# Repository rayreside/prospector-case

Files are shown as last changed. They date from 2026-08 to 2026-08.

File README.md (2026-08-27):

# Prospector Case

A compact 3D-printed case for the
[Prospector](https://github.com/carrefinho/prospector) ZMK dongle — a Seeed
XIAO and a round display, in a shell small enough to sit beside a keyboard
rather than in front of it.

42.8 × 43.0 × 35.4 mm assembled, two printed parts, 11.5 cm3 of plastic.

> ### ⚠ This is for the **beekeeb** Prospector
>
> It is cut around [beekeeb's Prospector kit](https://shop.beekeeb.com/products/zmk-wireless-dongle-prospector-diy-kit),
> and every dimension in it was measured off that build. Two things about it
> drive the whole design:
>
> - **beekeeb's adapter PCB** — the "hat" — sits on the XIAO and carries a
>   socket for the display's cable, so the link is a plugged cable at both ends
>   rather than eight wires soldered to the XIAO's pads. **That board is what
>   the case is shaped around.** It is what sets the depth, and every clearance
>   in the model is measured against it.
> - **No ambient light sensor.** There is no room for the sensor board and no
>   window for it.
>
> **On the original Prospector: this may or may not fit, and expect to modify
> it.** The upstream build solders the display straight to the XIAO's pads, so
> the stack is a different shape and sits at a different height — the hat is the
> single biggest thing this case is built around, and without it the interior is
> wrong. The numbers are all in the open and parametric, so adapting it is
> realistic work rather than a rewrite, but it is work. Start from
> [What it expects](#what-it-expects) and measure your own build first.

Every dimension is measured off carrefinho's published STLs and off the built
shell; no upstream geometry is copied. The measurements and the reasoning
behind each one are in [prospector/REFERENCE.md](prospector/REFERENCE.md), and
the design itself is documented in [prospector/README.md](prospector/README.md).

## What it expects

| | |
|---|---|
| Display | Waveshare 1.69" Touch LCD, 240 × 280, part **27057** — 41.13 × 33.13 mm, four M2 holes on a 29.93 × 22.57 pattern |
| MCU | Seeed **XIAO nRF52840**, soldered flat to the hat |
| The hat | beekeeb's adapter PCB, carrying a socket for the display's cable. The case has room for a stack **21.9 × 27.0 × 9.82 mm**, with the XIAO and its USB-C hanging *underneath* — the hat's own board sits 4.30 mm above the bottom of that stack, and its USB-C leaves along the 27 mm axis, flush with one end |
| Hat mounting | two M2 into printed pads, 17.10 mm apart, 2.65 mm in from the board's edge |
| Fasteners | **8 × M2** — four for the display into its own standoffs, two M2 × 6 for the rear cap, two for the hat |
| Cable | about 20 mm of clear run above the hat for the bundle to turn upward, which the model checks and echoes |

Those are the dimensions the case is cut to, taken off a beekeeb build.
Anything that fits inside them and puts its USB-C in the same place will go in.
**Measure yours before printing** — the three clearances that matter are echoed
on every build, so a changed number tells you at once whether it still fits.

## Printing

The STLs in [`release/`](release/) are ready to print and are what came off the
bed here — see [release/README.md](release/README.md) for figures to check them
against.

- **Shell** desk-down as modelled, with support. All of it is interior roof
  nobody sees.
- **Cap** standing on its bottom edge, with a brim.
- **0.20 mm layers**, whatever the printer: the joint steps are 0.80 and the cap
  is 1.60, and both divide exactly.
- Set the slicer's support threshold **below 44.81°**. The chamfered roof sits
  at exactly that, two tenths under the usual 45, and above the line it counts
  as an overhang when it is not one.

Assemble **hat first, display second, cap last** — the hat's screws are driven
straight down through the display opening, so the display has to go in after it.

## Building

```bash
openscad -D 'part="shell"' -D 'show_parts=false' \
         -o build/prospector_shell.stl scad/prospector.scad
openscad -D 'part="cap"' -o build/prospector_cap.stl scad/prospector.scad
```

`part` also takes `all`, which is the assembled view rather than something to
print.

`show_parts` ghosts the display and the XIAO in place. That is what you want on
screen and not what you want in an STL: left on -- and it is on by default --
the shell exports with both of them inside it, three shells and 27.20 cm3
against one and 9.62. The cap never draws them, so its line needs nothing.
Either way `tools/stlstat.py` says at once which one you have.

You do not have to build it to print it. [`release/`](release/) holds the two
STLs, checked in and refreshed with the geometry, so a `git pull` puts the
printable parts on disk -- with the figures to check them against and the
orientations to print them in.

## Checking it

`tools/` holds the verification scripts — cross-section diffs, thin-feature
detection, wall thickness, overhang and free-space analysis. They are described
in [tools/README.md](tools/README.md).

The habit they exist to support: a volume figure will tell you a part is 0.1%
off and never tell you which face moved. Measure where, not how much.

## Credits

- **[Prospector](https://github.com/carrefinho/prospector)** by **carrefinho** —
  the dongle this is a case for, and the design every dimension here was
  measured against. Licensed CERN-OHL-P-2.0.
- **[beekeeb](https://shop.beekeeb.com/products/zmk-wireless-dongle-prospector-diy-kit)**
  — the kit this case is actually cut around. Their adapter PCB is what makes
  the display a plugged cable at both ends, and it is the single component that
  determines this case's proportions. Their
  [build log](https://docs.beekeeb.com/build-guide/prospector-zmk-dongle-photo-build-log)
  is the reference for how the stack goes together.
- **[ZMK](https://zmk.dev)** — the firmware the dongle runs.
- **Waveshare** — the 1.69" Touch LCD Module (27057) the case is cut around.
- **Seeed Studio** — the XIAO nRF52840.

Named because the work stands on theirs, not because any of it is vendored:
no third-party file is checked in here, and no upstream geometry is copied.
[NOTICE.md](NOTICE.md) sets out that relationship, the licence each upstream
carries, and the reasoning about what is deliberately *not* in this repository.

## Licence

MIT — see [LICENSE](LICENSE). That covers the OpenSCAD sources, the Python
tools, the documentation and the STLs built from them.

**No warranty, and one caveat worth stating plainly:** this is a case measured
off someone else's hardware and printed on one printer. It fits a beekeeb
Prospector without the ambient light sensor. If yours differs — and an original
Prospector does differ — the numbers are all in the open. Change them and
rebuild rather than trusting these.

---

Split out of the Urchin case repository, which is where this work started; the
history came with it.

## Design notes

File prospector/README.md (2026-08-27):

# Prospector dongle case — compact

A smaller enclosure for a [Prospector](https://github.com/carrefinho/prospector)
built **without** the ambient light sensor, and with a **hat on the XIAO**
carrying a socket for the LCD cable — so the link is a plugged cable at both
ends rather than eight wires soldered to the XIAO's pads. That hat is what the
design is really shaped around.

Specifically, it is cut around
[beekeeb's Prospector kit](https://shop.beekeeb.com/products/zmk-wireless-dongle-prospector-diy-kit),
whose adapter PCB is that hat. An original Prospector solders the display
straight to the XIAO's pads and makes a differently shaped stack; this case may
or may not take one, and would need modifying to.

Model: [`scad/prospector.scad`](../scad/prospector.scad), hardware constants in
[`prospector_hw.scad`](../scad/prospector_hw.scad), measurements and their
provenance in [REFERENCE.md](REFERENCE.md). Built to `build/prospector/`.

## Where it stands

| | upstream, no sensor | this |
|---|---|---|
| Envelope | 43.2 x 51.4 x 38.0 | **42.8 x 43.0 x 35.4** |
| Enclosed | 59.86 cm3 | **42.59 cm3** |
| Plastic | 15.92 cm3 | **11.44 cm3** |
| Parts | 3 | 2 |

Same width, 16% shallower, 2.6 mm shorter, 29% less enclosed volume, 28% less
filament, and the screen keeps the upstream 55 degrees. Both parts watertight,
one shell each, zero boundary edges.

The width is the module's pocket plus a 1.7 bezel and cannot go below that.
Everything else saved is depth, and it comes from folding the boards together
instead of putting them at opposite corners of an empty box.

**The display face is flat.** `LIP_BORE` would recess the module's lip so it
finished flush, as upstream does, but that leaves a ring only 0.85 wide by
0.80 deep standing around it -- two extrusion widths and four layers, and it
does not print. Off, the face is one plane with the pocket's opening in it: the
lip lands on that face and stands 0.80 proud, and the material around the
opening is the full 1.7 bezel rather than a fragile ledge. 0.835 mm of case
shows around the lip, the same as upstream.

**And that frame is a constant width, which it was not, and getting there took
two goes.** The story is worth keeping in full, because the first attempt was
confidently wrong and every number in it was arithmetically correct.

The printed part showed a gap at each corner and nowhere else. The diagnosis
was that the section's corner radius, 7.00 and carried over as "the upstream
look", was not concentric with the pocket's 3.20: the frame narrowed toward the
diagonal, 1.70 at the sides against **0.83** at the corner, 0.829 measured off
the mesh, and the module's lip overhung the case by 0.13 mm there with nothing
under it. So the radius was made derived -- `DISP_R + DISP_CLR + BEZEL` --
which returned 4.90, and the corners filled in.

**Every one of those figures is downstream of `DISP_R`, and `DISP_R` was
wrong.** It said 3.00. Nothing had ever measured it; REFERENCE.md carries
provenance for every other number about this module and never mentioned this
one. Waveshare's panel table gives the corner as R5, and at R5 the whole
account inverts:

- **7.00 was already concentric.** It is what the identity above returns for a
  module of about R5.1, and upstream's own front face measures 0.835 of plastic
  round the lip -- uniform, corners included. Upstream had not been careless
  with a styling number; it had the radius right.
- **4.90 is now the mismatch.** Against the real module the frame runs 0.835 on
  the flats and swells to **1.705** at the corners -- the same fault mirrored,
  and visible in the model as corners that read too heavy.
- **Neither radius was ever the gap.** The pocket is cut to `DISP_R +
  DISP_CLR`, so at 3.00 it was 3.20 -- about two millimetres squarer than the
  module at every corner. The module's round corner sat in a squarer hole and
  left a crescent of open pocket. That is what the photograph shows. The
  module's own rim normally hides the pocket, and that is why it was marginal
  rather than obvious: at 3.00 the rim covers the corner by 0.865, at R5 by
  **0.037**, and a hair past that the pocket is exposed.

`DISP_R` is 5.00 now and `RIM_R` returns to 6.90 on its own. All four outlines
-- module, pocket, lip, case -- come out as the same 29 x 21 rectangle grown by
5.00, 5.20, 6.065 and 6.90, so every gap between them is constant: 0.200 of
clearance round the module, 0.865 of rim over the pocket, 0.835 of case round
the rim, corners and flats alike. The envelope does not move.

`LIP_W` and `LIP_H` were wrong too, and in a way worth naming: they were
41.33 x 33.33, read off **upstream's counterbore**, which is a hole and
therefore cut oversize. Waveshare give the module as 41.13 x 33.13. Taken as
the part it understated the frame round the lip at 0.735 against upstream's
0.835 -- which read as this case being the tighter of the two, when they are
identical. The check that settles it: with the part at 41.13 and `LIP_CLR` at
0.10, this model's own counterbore comes out at 41.33 x 33.33, reproducing
upstream's measured bore exactly.

**The lesson is not about corners.** A derived number is only ever as good as
what it derives from, and this one derived from the single figure in the file
that nothing had measured. `DISP_R = 5.00` is still the vendor's number rather
than a caliper on this part -- but it is now the *only* unmeasured input, and
three independent things agree with it where nothing agreed with 3.00.

## The clearances

The size is set by the hat and the cable, not by walls or the display. Every
gate is computed and echoed on every build, because not one of them is visible
in a render:

```
ECHO: "frame round the pocket 1.7 mm at its thinnest  (want 1.7, its width on the flats)"
ECHO: "case showing round the lip 0.835 mm at its thinnest  (want 0.835, ditto)"
ECHO: "hat clears the ceiling by 2.69987 mm  (want 2.5)"
ECHO: "plug room at the socket 7.04472 mm  (want 5.43)"
ECHO: "headroom over the hat 20.3755 mm  (want 20)"
ECHO: "tray kerbs from y 23.8195 to 41.4  (hat front 13.8)"
ECHO: "driver at the top screws 6.07027 mm across  (want 5)"
```

The first two are not clearances at all -- they are the front face, taken at
the corner rather than on the flats, because that is where the section's
rounding and the module's meet and where a mismatch between them shows first.

The 20 is measured off the real bundle, from the hat's board. The plug-room ray
carries only the plug's own reach; it used to carry the bundle's 15 mm as well,
which was double counting -- the bundle is checked by the headroom test, in the
direction it actually travels. SLACK is 2.5 because it binds at the hat's bare
front corner, where nothing but air passes.

Each of these has been wrong at least once in a way that only a number caught:

- **Hat vs ceiling** started as a test against the display's back plane treated
  as *infinite*, which silently forbade sliding the hat forward under the
  display's lower edge. The display is a bounded slab; the test is now against
  the actual pocket.
- **Plug room** was measured to the hat's front face at the module's centre
  height and read 3.58 mm. The hat is 9.8 tall and that centre is 17 up, so the
  hat is not there at all — a proper ray against its box gives 20.6.
- **Headroom** has an optimum, not a floor. The ceiling over the hat is the
  lower of the display's back plane rising toward the rear and the case's top
  face falling; the tallest point is where they cross, and the depth is chosen
  to land the hat's front edge on it.

## The screen angle is free

It is 55 degrees, the same as upstream, and it costs nothing. Every angle comes
out 43.0 deep; the shallower ones are slightly shorter:

| screen | lift | depth | height |
|---|---|---|---|
| 70 | 4 | 43.0 | 38.71 |
| 65 | 4 | 43.0 | 38.40 |
| 60 | 4 | 43.0 | 37.83 |
| **55** | **4** | **43.0** | **37.00** |

That sweep was taken at `DISP_LIFT = 4`; the case is now built at 3, one
millimetre lower and shorter throughout.

For most of this project the model insisted a shallower screen cost 5-7 mm of
depth, and it was wrong three separate ways, each found the same way -- by
being told the space was plainly visible on the assembled part:

1. **The skirt leaned forward.** Below the display the case reaches the desk by
   extending its cross-section down the *screen plane*, so at a shallow angle
   it threw material forward instead of dropping: 7.10 mm at 55 against 2.04 at
   70. Trimmed vertically at the rim, and the depth difference vanished.
2. **The ceiling test subtracted a wall that was gone.** After the seat was cut
   back to a rim the window is open above the hat, so what is overhead is the
   module itself -- not a plate 1.6 below it. And 1.6 was being taken
   vertically when it is measured along the normal. Over the hat's front corner
   that was 0.99 reported against 2.59 real.
3. **The cable's headroom was measured from the socket**, 3.92 mm above the hat
   it had been measured from.

What remains true is that a 31 mm display at 55 lies over 17.8 mm of the case's
depth against 10.6 at 70. That is real, and it is why the *interior* is
shallower behind the module at 55 -- but it does not reach the outside, because
the depth is set by the hat, not by the display.

## The form

Underneath the rounding, the upstream case is a rounded-rectangle prism whose
axis is the screen normal, trimmed by the desk plane and a vertical back wall.
This is the same prism with the back pulled forward and its top-back corner
chamfered off — which is where the volume actually was. The chamfer stops short
of a clean triangle on purpose: a single line from the apex to the bottom-back
corner has to clear a 9.8 mm brick sitting 45 mm out, and solving that puts the
case at **69 mm** deep. The hat owns the bottom-back corner.

## What holds what

| part | held by |
|---|---|
| display | drops in from the front, lip lands on the flat face, 4 x M2 from inside into its own standoffs |
| rear cap | 2 x M2 into posts at x = +/-16; carries the chamfered roof too |
| hat | two M2 into pads at its own hole positions |
| cable | two posts to zip-tie the bundle down, clear of the seat's bosses |

The display goes in from the **front** and its own lip lands on the case — not
fed in from behind and trapped under a lip on the case, which is what the model
did first. The upstream mount settles it: 39.09 x 31.09 straight through, then
out to 41.33 x 33.33 for the last **0.80 mm** before the rim. So the case never
sits over the glass, and how close the picture runs to the module's edge stops
mattering.

**The shell's own roof needed its thickness stated.** Between the display and
the cap the outer face is the chamfer, and for a long time the inner face was
just wherever the cavity prism's top face happened to fall. Those two planes
converge and cross at y = 30.2, so the roof ran out as a wedge — 0.59 mm thick
at y = 29, 0.27 at 29.9, nothing at the seam. On the printed part the feather
edge tore off and left an open slot along the top of the cap, which is what it
looked like: a gap where the cap meets the case. The cavity is now bounded by
the cap's own inner face forward of `SPLIT_Y`, so the shell's roof is the same
1.6 plate the cap is and the two butt flush. Behind the split that bound does
nothing, which leaves the deliberate overrun as the only thing describing that
surface — the arrangement that got the self-intersections down from 219.

The seat is a 1.6 rim with an 8 mm pad at each screw, and nothing in between.
It was a 7.25 ledge until it became clear it was holding nothing: the module
front-loads and its lip lands on the face, so nothing can fall inward. All the
ring ever carried was the four screws. Before that it was 2.50, and all four
holes fell inside the connector window with no material under them — a case the
display could not be screwed to, invisible in every render.

The cap is a **bent panel**: the vertical back and the chamfered roof in one
piece. It has to be. The display's upper screws run along the screen normal,
and with the roof fixed to the shell the driver's line is blocked by the roof's
rear edge; taking the roof off with the cap clears it, and the fattest shaft
that then reaches them is **5.61 mm**, echoed on every build. The alternative
was access holes through a visible face. It is also much the larger surface, if
it is going to carry anything printed on it.

> The cap was split into a roof tile and a back plate for three commits, so
> each half could print the way it wants — the tile flat with its show face up,
> the back plate on its bottom edge — held by a ledge at the front and a groove
> at the rear, with no third screw. The mechanism was sound and it is in the
> history at `bee6b9a`. What sank it is that a 1.6 mm plate has to be split
> three ways to make that joint: lip 0.80, groove 0.80, tongue 0.65, with a rib
> hanging below. No margin anywhere, and the rib was rooted in **0.15 mm** of
> neck until a side elevation caught it — every mesh check passed, because
> 0.15 mm of neck is still one shell.
>
> The bent panel's only cost is that the roof's outer face prints against the
> build plate. The split's cost was every feature in it having none to give.

### The seam

The cap does not merely meet the shell at y = 30, it laps under it. The shell
keeps the outer 0.80 of the chamfer for 2 mm past `SPLIT_Y`; the cap's roof tip
is the inner 0.80 and stops 0.30 short. Sectioned at y = 31 the shell holds
24.713..25.840 and the cap 23.585..24.713 — meeting on a plane, so the shell
also holds the roof down rather than only abutting it.

It is a lap because the butt did not work, for a reason that showed up only on
the part. Two faces in different planes — the back at y = 41.4 and the roof tip
at y = 30 — were both required to close in the same instant, on two separately
printed parts. Whichever lands first wins, and it was the tip: the back plate
could not close, the screws kept pulling, and the roof bent backwards. The
clearance now goes in y, where the lap hides all but a 0.3 line.

**The lesson, which cost a print.** A zero-volume intersection between two parts
says they do not overlap. It does not say they can be assembled. A face square
to the direction of travel must not touch before the seating face does, and no
static check in this repo can see the difference.

**And a second lesson, from the same seam: that section above was computed, not
measured, and for a long time it was not true.** The lap is described here as
the outer 0.80 of the chamfer, and `seam_lip()` draws exactly that -- but it was
never unioned into the shell. Leaving it out of `cap_void()` only stops the
cap's region taking it away; it does not put it there. What was actually left
behind the split was whatever `outer()` minus `hollow()` happened to leave, and
behind `SPLIT_Y` the cavity is deliberately unbounded above, so the roof there
was governed by the cavity prism's own top face -- which crosses the chamfer.

The lap came out as a WEDGE, and every millimetre of it was under one extrusion
width:

    y = 30.0   0.44 mm       y = 31.2   0.08 mm
    y = 30.5   0.30          y = 31.4   0.02
    y = 31.0   0.14          y = 31.5   nothing

So from y = 31.5 to where the cap's own skin starts at 32.3, **no part owned the
roof at all** -- an open slot about 1.5 mm wide, plus whatever of the feather
edge tore off in the printing. It is the same failure as the roof forward of the
split, which was fixed by bounding the cavity with the cap's inner face; this
side kept the fault, because the fix was never applied to the material the lap
is made of.

`seam_lip()` is unioned on now. The lap is 0.80 thick over its whole 2 mm, the
figures above are measured off the mesh rather than derived, and the 30.7 x 0.40
sliver that `thin.py` had been reporting at z = 26 -- and that had been written
off as inherent to the joint -- is gone with it.

**The line that is left is meant to be there, and it is now two numbers rather
than one.** `SEAM_CLR` was doing both ends of the lap at 0.30, and they are not
the same problem:

- The **tongue's tip**, against the shell's roof end at `SPLIT_Y`. It sits under
  the lap where nothing can see it, and it is the clearance that bent the roof
  backwards when it was zero. `SEAM_CLR`, still 0.30.
- The **cap's shoulder**, where its skin steps back up to full thickness against
  the trailing end of the lap. Neither part owns the roof across it, so this is
  the visible line -- and on a 45 degree roof it opens up by 1/cos, showing 1.41
  times its own width. At 0.30 that was 0.42 mm of open groove 0.80 deep, which
  is a mark, not a hairline. `SEAM_SHOW`, now **0.15**, showing 0.21 and echoed
  on every build.

Tightening only that end is safe in a way tightening both would not be. If the
shoulder binds, the cap stops 0.15 short of a seat two screws are pulling it
onto, over a step 0.80 deep, and it shows as a gap at the back plate. If the
**tip** binds it levers the whole roof, which is the failure this joint exists
to avoid. What the shoulder has to absorb is the difference between two
nominally 9.4 mm runs from each part's seating face -- and both are plain y
positions, vertical walls placed by XY motion on both parts rather than
layer-quantised, so it is XY accuracy twice over and nothing worse.

### The rear screws

The pilot has been wrong in both directions, which is worth recording because
neither number was arbitrary and both were still wrong:

| | | |
|---|---|---|
| 2.10 | screws spun straight through | sized for the M2.5 in upstream's BOM, above an M2's own major diameter |
| 1.60 | driver cammed out; head crushed into the plate | 0.8 x major, the textbook thread-forming pilot |
| **1.70** | | the pilot the **hat** screws use — same screw, same plastic, and the only one here that has been driven without complaint |

Both now come off `M2_PILOT`, so they cannot drift apart again.

The "head sinks in" half of that was the same fault seen from the other end,
not a second one: 4.4 mm of thread to form at once takes more torque than an
M2 head will take, and once the driver slips the head crushes 1.6 mm of plate.
Peak torque is the pilot times how much thread is being formed at once, and the
second term was free — `CAP_FREE` bores the post's mouth to clearance for
1 mm first, so an M2 x 6 forms **3.4 mm** of thread rather than 4.4, and finds
the hole square before it starts biting. The bore's lip is broken by 0.30 so
the head beds on flat material.

`CAP_HEAD` is `"pan"`. If the screws turn out to be **countersunk**, set it to
`"flat"` and the chamfer becomes a real 90-degree seat to `CAP_HEAD_D` instead
of an edge break — with a conical head in a straight 2.2 hole the head wedges
and buries itself no matter what the pilot does.

The hat drops onto pads at its own hole positions and takes two M2. With the
seat cut back to a rim a driver comes straight down through the display
opening, so the order is hat first, display second.

`MCU_HOOKS` adds rails along the top of both side kerbs, which capture the hat
without screws -- the kerbs already stand 0.9 mm proud of the board, so it
costs 1.2 mm of height and 99 mm3. Off, because the screws already do the job
and the rails' undersides are 107 mm2 of horizontal ledge to support. Worth
remembering that rails work where hooks did not: an earlier version reached
back over the hat's front corners, so the board had to slide *into* them, and
everything ahead of it blocked that in turn.

**The kerbs themselves stop at y = 25.2, not at the hat's front edge.** The
display's two lower access bores come down through exactly that space -- they
leave the bosses at 55 degrees and reach the desk around y = 22 -- and the
tray's outer corners sit on their line. Run the full length, the bores notch
each kerb over 8 mm of a 1.5 mm wall, which is what it looks like on the part.
`KERB_Y` is derived from the bore rather than typed in, and it is deliberately
about 2 mm conservative: it asks the whole 5 mm bore to be clear, not just the
0.29 mm sliver that actually overlaps, so it does not quietly go wrong if the
kerb moves. 16.2 mm of kerb is left, against the two screws at the front and
the cap behind. What the bores still graze is the 0.6 mm standoff pad, out
where it overhangs the board -- and they pass through the floor there anyway.

**The XIAO and its USB-C hang underneath**, propping the board 4.30 mm above the
bottom of the stack. Missed on the first test print, where the pads had been
drawn up to the stack's underside with no board there to meet them.

The alternative, if a bolted hat is ever wanted, is to move the pads onto a
tongue on the rear cap: the hat then bolts to the cap on the bench and the pair
slide in together. One more feature, no more parts.

> A feature that adds no material can still break the mesh. With `BOSS_H = 0`
> the seat's boss cylinders sat entirely inside the plate that already existed
> — zero volume — but their front faces landed exactly on the seat's front
> plane, and that coplanar contact was the shell's one non-manifold edge. The
> fix was not to draw them. Found by elimination: `outer()` and
> `outer() - hollow()` were both clean, so it had to be something unioned on
> afterwards, and the edge sat exactly on `w = 0`.
>
> Anything added inside the shell has to be unioned **after** `hollow()` is
> subtracted, or the cavity swallows it — built the wrong way round, the seat
> bosses, the tray and the cap posts all vanished and the shell came back at
> exactly the volume it had without them. Then they have to touch something: a
> post floating at screw height and a tray sitting flush on the floor both came
> out as separate shells until given a foot and a 0.2 mm overlap.

## Printing

**Shell desk-down as modelled; cap standing on its bottom edge, with a brim.**
Measured with `tools/overhang.py`, and it contradicts the obvious guess — that
the sloping interior roof made desk-down the bad orientation:

| | support | bed contact | height |
|---|---|---|---|
| **shell, desk-down** | 555 mm2 | **1446 mm2** | 35.4 |
| shell, front face down | 538 mm2 | 240 mm2 | 36.7 |
| shell, back face down | 504 mm2 | 117 mm2 | 41.4 |
| **cap, as modelled** | 638 mm2 | 69 mm2 | 26.8 |
| cap, laid flat | 0 mm2 | 378 mm2 | 13.0 |

**Read that table with the threshold in mind.** At `DISP_LIFT = 3` the chamfer
sits at **44.81 degrees** from horizontal, two tenths of a degree under the
45 the tool defaults to, and the whole 638 mm2 on the cap is that one surface
crossing the line. At `--thresh 44` the same orientation scores 20 mm2. Nothing
about the part got harder to print between 46.5 degrees and 44.8; set the
slicer's threshold to 40 and the cap still prints standing, as it did before.

All the shell's support is interior roof that nobody sees. The cap needs almost
none standing up, but 69 mm2 of contact under a 27.6 mm part wants a brim.

The tool ignores shallow faces within 1 mm of the bed, which matters: without
that the 0.80 mm counterbore ledge scored 153 mm2 against an orientation where
it was really just the second layer. **It also hides things.** On the split
roof tile it reported a clean 0 mm2 while a 2.9 mm ledge floated 0.80 above the
bed -- inside the exemption, and a mating face. Pass `--above 0` before trusting
a zero, and read the heights rather than the total.

Settings the geometry dictates, whatever the printer: **0.20 layer height**,
because the joint steps are 0.80 and the cap is 1.60 and both divide exactly;
thin-wall detection on; and support for the shell only. The cap standing up
needs almost none, and support anywhere near the display seat has to come back
out through the pocket.

## Still to do

- ~~Shell and cap meet at exactly 0.00~~ — **this was the wrong conclusion, and
  the printed part proved it.** Intersecting the two solids gives zero volume,
  and I read that as a butt joint located by two screws, which is what it should
  be. Right about the y = 41.4 plane, blind to the other one: the cap's roof tip
  met the shell's roof edge at y = 30, also at exactly 0.00, and that face is
  square to the direction the cap travels to seat. On the part the tip landed
  first, the screws kept pulling, and the roof bent backwards — opening the very
  gap the joint was meant to close. The seam is a lap now; see below.
- **The cap's bottom-back fillet reaches 0.12 mm from the hat.** The `BACK_R`
  rounding where the cap meets the desk curves forward of y = 41.4 by 0.18, and
  the hat's rear edge is at 41.1. Positive, but it is the tightest unintended
  clearance in the case and nothing checks it.
- **Three self-intersecting triangle pairs and twelve degenerate faces** remain
  in the shell, out of 3394. Down from 219, which is what the slicer was
  visibly choking on. Slicers deal with what is left routinely.
- **`PLUG_H` is the one estimated number** — 4 mm, inferred from the hat's 9.82
  stack rather than measured. The plug-room check has 8.79 against a need of
  5.43, so it does not fail until `PLUG_H` exceeds 7.36.
- **The socket's position across the module is still unknown**, only that it is
  on the left. `CONN_SLOT_*` is a generous relief rather than a fitted pocket.
- **No full assembly has been printed.** The shell has been through several
  test prints; the cap has not. The rear screws have, and drove badly enough to
  change the pilot twice — see above.

## Layouts that were considered and dropped

| | screen | depth | height | why not |
|---|---|---|---|---|
| slab, boards back to back | 55 | 41.6+ | 36.5+ | `GAP` must be 15 for the bundle, which puts it past 45 deep; stands on 13.7 mm of base |
| tail out the back | ~90 | 42 | 34 | needs a near-vertical screen |
| hat under the display | 75 | 30.0 | 52.8 | 52.71 cm3 — same volume, trades 19 mm of depth for 16 of height |
| hat turned, USB out the side | 70 | ~42 | 38.7 | 5 mm shallower, but the USB-C leaves sideways |

`scad/prospector_slab.scad` still builds the slab if it is ever wanted.
`DISP_LIFT = 18, DEPTH = 30, TILT = 75` builds the hat-under variant;
`-D MCU_DY=MCU_D -D MCU_DX=MCU_W` turns the hat.

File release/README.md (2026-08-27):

# Printable exports

The two STLs beside this file are what comes off `scad/prospector.scad`. They
are checked in so that a `git pull` puts the printable parts on disk -- the
repository is the sync channel, and not everyone who wants to print this has
OpenSCAD installed.

Built with OpenSCAD 2021.01, from the commits that unioned the seam lip into
the shell and tightened the shoulder behind it. Before them the lap over the
rear cap was a feather edge, with an open slot about 1.5 mm wide behind it and
a 0.42 mm groove behind that; what is left is a 0.21 mm line.

| | shell | cap |
|---|---|---|
| triangles | 3550 | 864 |
| bounding box | 42.800 x 41.400 x 35.368 | 42.800 x 12.700 x 25.408 |
| volume | 9.6219 cm3 | 1.8788 cm3 |
| shells | 1 | 1 |
| non-2-manifold edges | 0 | 0 |
| boundary edges | 0 | 0 |

`python tools/stlstat.py release/prospector_shell.stl` reproduces that column,
which is the check that you have the file you think you have. The shell at
27.1 cm3 and three shells is the one with the ghosted display and XIAO
exported inside it -- see below.

## Printing

**Shell desk-down as modelled.** 678 mm2 of support and **1414 mm2** of bed
contact, against 117 mm2 back-down -- and all of that support is interior roof
nobody sees. Measured with `tools/overhang.py`, not reasoned about; it
contradicts the obvious guess about the sloping roof.

**Cap standing on its bottom edge, with a brim.** Its 622 mm2 is very nearly one
surface, the chamfer, sitting at 44.81 degrees -- two tenths under the 45 the
tool defaults to. At `--thresh 44` the same orientation scores **20 mm2**, so it
needs almost no support standing up; what it does need is the brim, because
69 mm2 of bed contact under a part 25.4 mm tall is not enough on its own.

The shell reads the same way: 678 mm2 at 45 degrees, **435** at 44. Set the
slicer's threshold below the chamfer's own angle and most of both figures goes
away, because most of what they count is that one surface.

**0.20 layer height**, whatever the printer: the joint steps are 0.80 and the
cap is 1.60, and both divide exactly. Support for the shell only -- anything
near the display seat has to come back out through the pocket.

The full orientation table and what the overhang tool hides are in
[../prospector/README.md](../prospector/README.md).

## Rebuilding

```bash
openscad -D 'part="shell"' -D 'show_parts=false' \
         -o release/prospector_shell.stl scad/prospector.scad
openscad -D 'part="cap"' -o release/prospector_cap.stl scad/prospector.scad
```

`show_parts` is on by default and ghosts the display and the XIAO in place. On
screen that is the point; in an STL it is the display and the XIAO exported
inside the shell -- three shells and 27.20 cm3. The cap never draws them, so
its line needs nothing.

Two things follow from checking these in:

**They go stale silently.** Nothing rebuilds them. Anything that changes the
geometry has to rebuild both and commit them in the same commit, or the files
here describe a case that no longer exists.

**Do not diff them by hash.** OpenSCAD does not emit facets in a stable order,
so two builds of the same tree give two different files with the same triangle
count and the same vertex set. `stlstat.py` is the comparison that means
anything; `md5sum` is not.

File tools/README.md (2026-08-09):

# Verification tools

Used to check `scad/prospector.scad` against measurements taken off the
upstream STLs. The measurements are the ground truth; the model is checked
against them, never the other way round.

Requires Python 3 and numpy. Both scripts read ASCII and binary STL.

## `stlstat.py` — bulk properties

```bash
python tools/stlstat.py build/prospector_shell.stl
```

Reports triangle count, bounding box, volume, shell count, and edge
manifoldness. It reproduces the figures published in the root README exactly,
which is the check that it is measuring correctly.

Note: the non-2-manifold edge count here (25 on the top) is higher than the 17
the README cites from Blender — a different counting convention. Both agree on
zero boundary edges, which is what actually determines watertightness.

## `slice.py` — cross-section areas

```bash
python tools/slice.py <reference.stl> <candidate.stl> 2.0 3.0 4.5 8.5
```

Prints the cross-sectional area of both meshes at each z, with the delta.
Volume alone says *how much* two parts differ; this says *where*. A constant
delta across a z band means both parts are prismatic there and the section
itself is wrong. A delta that varies with z means the reference has features
the candidate lacks.

## `clusters.py` — where two sections disagree

```bash
python tools/clusters.py <reference.stl> <candidate.stl> 6.0
python tools/clusters.py ref.stl cand.stl 6.0 0.025 0.02   # step, min area
```

Labels the disagreement into connected clusters and gives each one's extent, in
both directions separately. `slice.py` says how much and at what height; this
says whereabouts, which is the part that leads to a cause.

Splitting the two directions matters. The mountains once read −0.14% on volume
because a 12 mm² deficit on one wall was cancelling a 12 mm² surplus elsewhere;
fixing the deficit made the total look worse and the part better.

## `thin.py` — features too thin to print

```bash
python tools/thin.py build/prospector_shell.stl 6.0 0.20
```

Opens the section with a disc and reports what the opening removed — anything
narrower than twice the radius cannot hold the disc. Pass about half a nozzle
width. Convex corners lose only r²(1−π/4), so a hit near that size is noise.

This found what diffing could not. The printed mountains carry no feature under
0.4 mm anywhere; the port had eighteen, one of them a 5.70 mm tongue just
0.047 mm wide, which a 0.10 mm section grid had stepped straight over.

It also brackets a threshold from both sides: if the printed part drops a 0.437
sliver but keeps a 0.485 strip, the radius that reproduces it is pinned to a
window rather than fitted to a curve.

## `fitedge.py` — is this edge straight, and at what angle

```bash
python tools/fitedge.py <part.stl> 6.0 128.4 135.0 44.0 86.0 max
```

Traces one boundary of the window row by row and fits a line. The residual is
the useful part: at the raster floor (`step/√12`) the edge is exactly straight
and the angle can be trusted; well above it, the window spans more than one
edge and the fit means nothing.

Check an angle at two heights before believing it. If they differ the part
isn't prismatic and one section was never going to describe it.

## `raster.py` — shared section fill

Not run directly. `clusters.py`, `thin.py` and `fitedge.py` all fill a section
onto a grid through it.

Both crossing tests are half-open rather than strict, which is not fussiness:
the strict form drops any segment with an endpoint exactly on the scan line,
and on a tessellated mesh vertices land on round coordinates constantly.
`probe.py` had that bug and it dropped two of four crossings at y=20 on the
printed mountains — and because the survivors are paired off in order, the
spans it printed were plausible and wrong.

**Resolution is the recurring trap in all of these.** A feature thinner than
one cell can vanish entirely. An edge that merely crosses a cell boundary
during a parameter sweep reads as a whole cluster appearing, which looks like a
cliff in the numbers and is not one. Keep the step well under the smallest
thing being judged.

## Seeing anything in the OpenSCAD GUI

Two settings do almost all the work, and both are off by default:

- **View -> Show Edges.** Without it a plate is a flat slab and features
  disappear into it.
- **F6 (Render) rather than F5 (Preview).** Preview draws subtracted volumes
  as green ghosting; F6 shows the actual solid.

Perspective rather than orthographic also helps read depth. Even so the
viewport has no shading worth the name -- for judging outside shape, export
with `build.py` and open the STL in a real viewer.

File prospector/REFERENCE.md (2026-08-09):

# Prospector dongle — measured reference

Everything here was measured off the upstream case
([carrefinho/prospector](https://github.com/carrefinho/prospector), `case/`),
not read off a datasheet. Waveshare publishes no usable drawing for the module
and the vendor pages return 403 to anything but a browser, so the display
outline below is derived from the pocket that holds it.

Tools used: `tools/loops.py` (tilted sections, loop by loop),
`tools/stlstat.py` (bulk properties), `tools/void.py` (where the air is).

## What the stock case costs

| | |
|---|---|
| Envelope | 43.2 x 51.4 x 38.0 mm |
| Convex-hull volume | 59.86 cm3 |
| Plastic | 15.92 cm3 |
| Free interior | 43.94 cm3 — **73% air** |

Parts: `main_body_no_sensor` 7.137 cm3, `rear_cap` 5.785 cm3,
`disp_mount` 3.002 cm3. All three are watertight, 0 boundary edges.

The three STLs share one origin, so they can be imported together and measured
as an assembly without any transform.

## Why it is that size

Not the width. The front face is 43.0 x 35.0 mm around a 39.09 x 31.09 pocket:
a **1.95 mm bezel**, already near the floor. About 0.5 mm is recoverable there
and no more.

The depth and the height. The two boards sit at opposite corners of an empty
shell — display at the front top, XIAO flat on the floor at the back — so the
wire run is a ~45 mm diagonal across a box that is otherwise air. The bezel
frame alone is 10.6 mm deep from the body face to the front rim, most of that
a styling recess around the glass.

## Screen plane

**55.000 degrees from horizontal.** Recovered from the area-weighted face
normal (0, -0.819, 0.574) = (0, -sin 55, cos 55), which is exact to the 0.01
rounding of the normal cluster.

Nothing about the display is measurable in the export frame. `tools/loops.py
--tilt 55` sections in the screen's own frame; `u` is across the screen, `v` up
it, `w` out of it, with `w = 0` at the export origin and `w` increasing
forward.

| Feature | w (mm) |
|---|---|
| Body screw tabs | 4.40 -> 6.40 |
| Body front face (pocket floor) | 6.40 |
| Mount screw tabs | 6.50 -> 8.50 |
| Mount front rim | 17.00 |

## Waveshare 1.69" Touch LCD Module (27057)

| | |
|---|---|
| Outline | **39.09 x 31.09** mm pocket -> module ~39.0 x 31.0 |
| Mounting holes | 4 x M2, **29.93 x 22.57** mm pattern, 2.40 mm clearance |
| Orientation | landscape — 280 px across, 240 px up |
| Active area | 32.58 x 27.93 mm (1.69" diagonal, 0.1164 mm pitch) |
| Bezel on the module | 3.25 mm each side, 1.58 mm top and bottom |
| Thickness to the standoff tops | **9.96** mm (measured) |
| Thickness to the connector, its tallest point | **11.39** mm (measured) |

The hole pattern is not quite symmetric about the pocket: centres come out at
u = +14.922 and -15.008. Measured, not assumed; do not round it to +/-15.

The module carries its **own standoffs** on the back, and its four mounting
holes are real holes through it — so the seat in the case bears on the standoff
tops at 9.96, and the connector stands **1.43 mm proud of that** and needs a
relief. The CAD could not have given either number: from the upstream pocket
alone the module could have been anything up to 8.5 mm thick, which turned out
to be wrong in the other direction.

### Wiring

The module carries a **12-pin connector** on its back, not solder pads: VCC,
GND, LCD_DIN, LCD_CLK, LCD_CS, LCD_DC, LCD_RST, LCD_BL, TP_SDA, TP_SCL,
TP_RST, TP_IRQ. The supplied cable plugs in; upstream cuts the four TP_* wires and solders the
remaining eight to the XIAO's pads. **The build this is for does not** — see
below; it plugs into a hat at the far end too.

Either way the display end is a plug, and the connector body plus the cable's
bend radius set a hard standoff behind the module. The upstream body has a
39.09 x 17.57 mm window in its front face, centred on the module, purely to
clear that connector and cable.

The connector sits on the **left** as you face the screen — `-x` in the model's
frame, on the right if you are looking at the back of the board.

## The build this is actually for — not stock

The unit being designed around is **not** the upstream wiring. The XIAO carries
a **hat with its own connector for the LCD cable**, so the link is a plugged
cable at *both* ends rather than eight wires soldered to the XIAO's pads.

Measured:

| | |
|---|---|
| Hat outline | **21.9 x 27.0** mm |
| Hat mounting holes | **17.10** mm apart, **2.65** from the south edge, **2.10** dia |
| Whole stack, USB-C shell to the hat's socket | **9.82** mm |
| Glass to the end of the USB-C, boards perpendicular | **~36** mm |

The XIAO is soldered flat to the hat with no gap. The hat runs past it to the
south for two mounting holes; the USB-C is at the north end and exits in-plane,
off the board's edge. The hat's socket is on the **opposite face** from the
USB-C and its cable leaves **perpendicular to the board**.

That last point drives the layout. The socket has to face into the cavity, so
the assembly goes in inverted relative to the stock build — XIAO down, socket
up — which also drops the USB-C to the bottom of the stack where it wants to be.

**The hat is 5.81 cm3 against a bare XIAO's 1.61.** With the display's 12.04
that is 17.9 cm3 of hardware, in a stock case enclosing 59.9 — only 30% full,
but the free space is the wrong shape, not surplus.

Reset access **is** required, reversing an earlier note here that said it was
not. The button had gone unused for months, which is why the case was built
without it; it is wanted now.

It faces **down**, at the case's floor. The XIAO hangs under the hat and the
whole stack is inverted, so the component side the button sits on points at the
underside -- upstream's cantilever tab in the rear cap was for a bare XIAO the
other way up and does not transfer.

The XIAO's **USB-C edge sits flush with the hat's north edge** -- measured. With
the hat at y = 14.1..41.1 and the board 21.0 x 17.5, that puts the XIAO at
y = 20.1..41.1, x = +/-8.75, and leaves exactly the 6 mm strip to the south that
carries the mounting holes. The button is beside the USB-C, so it is up at the
y = 41 end -- the far end from both screws, which is why the retaining rails had
to come back.

Measured from two datums, and they agree: **0.5 mm from the board's outer edge**
and **2.85 mm from the connector's face**, the difference being a 2.35 Type-C
overhang. What is *not* settled is whether either is to the button's centre or
its near edge, and its offset across the board is not measured at all.

**Which side: the +x side**, the right as you face the screen. Reported as "to
the left of the port, looking at the bottom with the port pointing up" -- a
mirrored view. Seen from outside the underside, +y cross +x = -z points at the
viewer, so +y to +x is counterclockwise, which is their left. So their left is
our +x. The button therefore sits at roughly x = +6, y = 40.6.

The case does not need those numbers. Rather than a pin hole that has to be
aimed, the floor is cut away in a strip from y = 38.1 back to the shell's rear
edge, 18 wide -- open at the back, so the y datum does not matter, and wide
enough that a pin reaches |x| = 8. Verified by standing a 1.5 mm column at
several offsets and intersecting it with the built shell.

### What this rules out

The screen angle is the binding constraint, not the wall thickness and not any
cleverness in the layout. At the upstream 55 degrees the display's back plane
climbs over the hat too slowly, and the case can only be made to fit by raising
the display 10 mm — at which point the skirt that brings it back down to the
desk juts 10.4 mm forward and the whole thing comes out **bigger than
upstream**, 55.4 x 43.4 against 51.4 x 38.0.

70 degrees is the minimum of that curve. The full sweep is in the case README.

## Seeed XIAO nRF52840 — bare, for reference only

Not what is being designed around; see the hat above. 21.0 x 17.5 x 3.5 mm,
about 4.5 mm over the USB-C shell.

In the stock case it lies flat on the floor at the back, USB-C out the rear
face through a **9.5 x 3.75 mm** slot centred at x = 0, z = 5.355. The rear
cap carries a 1.8 mm wide cantilever tab beside that slot — the external reset.

Rear cap also has two 6.0 mm counterbores at x = +/-16.55, z = 14.33 for the
M2.5 x 4 screws that hold it on.

## Fasteners

| Screw | Count | What |
|---|---|---|
| M2 x 6 | 4 | display / mount / body sandwich |
| M2.5 x 4 | 4 | rear cap, and the sensor board upstream |

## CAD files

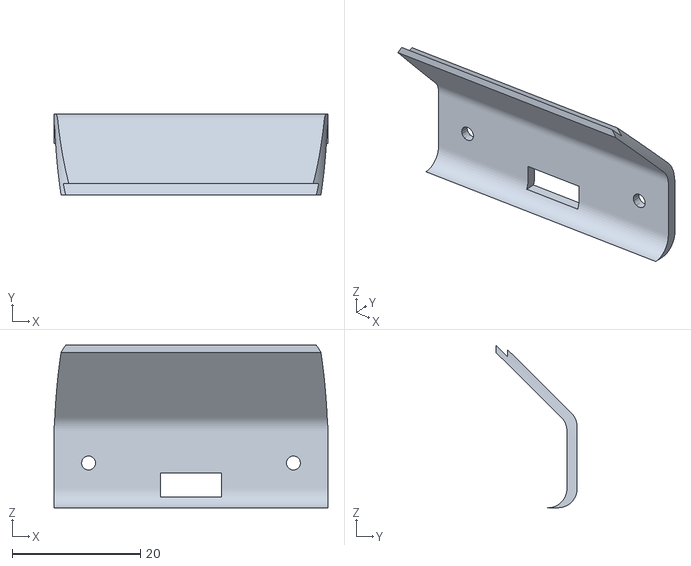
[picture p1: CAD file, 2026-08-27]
release/prospector_cap.stl
42.8 x 12.7 x 25.4

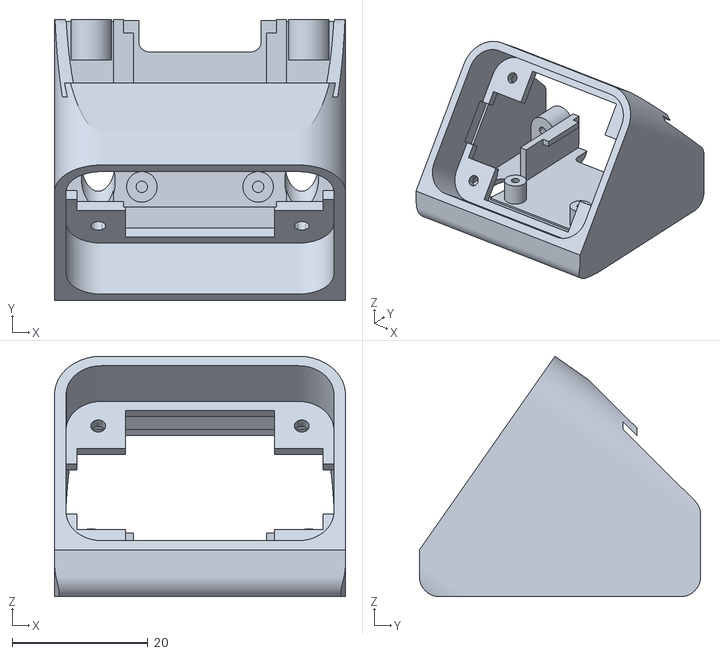
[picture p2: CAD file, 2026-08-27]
release/prospector_shell.stl
42.8 x 41.4 x 35.4

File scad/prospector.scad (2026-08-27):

// Prospector dongle case -- compact variant, no ambient sensor.
//
// FRAME. +x right as you face the screen, +y away from you, +z up, z = 0 is
// the desk. The canonical view is the front elevation, looking along +y. Every
// unqualified up/down/left/right in this file means that view. Sections are
// taken in the y-z plane, which is where all the interesting geometry lives --
// the model is symmetric about x = 0.
//
// FORM. The upstream case is, underneath the rounding, a rounded-rectangle
// prism whose axis is the screen normal, trimmed by the desk plane and by a
// vertical back wall. Measuring it that way (see prospector/REFERENCE.md) is
// what makes this parametric: the cross-section is pinned by the display and
// cannot shrink, so DEPTH is very nearly the only size knob, and pulling the
// back wall forward lowers the case at the same time as it shortens it,
// because the top face slopes back and up.
//
// PRINTING. Shell desk-down as modelled; cap standing on its bottom edge, with
// a brim. Measured with tools/overhang.py, not reasoned about:
//
//     shell   desk-down     555 mm2 support, 1446 on the bed
//             front down    538                240
//             back down     504                117
//     cap     as modelled   638 mm2 support,   69 on the bed  <- 44.8 deg,
//             laid flat       0                378     see README
//
// All the shell's support is interior roof that nobody sees.
//
// WHAT SETS THE SIZE. Not the walls and not the display -- the hat. It is 27
// long front to back and 9.8 tall, and the display's back plane has to climb
// over it before the case can end. Three clearances gate the depth and all
// three are echoed on every build.
//
// The screen is at the upstream 55 and costs nothing for it. For a long time
// this file claimed a shallower screen bought depth back; that was three
// separate modelling faults, and prospector/README.md records them.

/* [What to build] */
part  = "all";        // all | shell | cap
cut   = "";           // "" | x | y | z   -- section it, see CONTEXT.md
cut_at = 0;
cut_flip = false;
show_parts = true;    // ghost the display and the XIAO in place

$fa = 2; $fs = 0.4;

include <prospector_hw.scad>

/* [Geometry] */
BACK_CHAMFER = true;  // break the top-back corner, per the sketch
BACK_R    = 3.00;     // rounding where the back wall meets desk and top
// The seat has to be wide enough to carry the module's own mounting bosses,
// which is what sets 7.25 rather than anything to do with stiffness. At the
// 2.50 it started at, all four of the module's holes fell inside the connector
// window with no material under them -- a case the display could not be
// screwed to, and nothing in a render would have said so.
// The seat is no longer a ledge, because it was never doing the job of one:
// the module front-loads and its lip lands in the counterbore, so nothing can
// fall inward. All the ring was ever holding was the four bosses. What is left
// is a thin rim and a pad at each boss to tie it to that rim.
SEAT      = 1.60;     // rim around the pocket
SEAT_PAD  = 8.00;     // square of seat kept at each boss
BOSS_D    = 5.00;     // material kept around each screw
// Zero, and it should stay zero. The module brings its own standoffs, so the
// seat only has to be thick enough to pass a screw -- upstream's is a plain
// plate with holes and nothing more. A boss standing into the cavity just adds
// its height to what the screw has to cross before it reaches the standoff,
// and at 2.40 an M2 x 6 ran out of thread before it got there.
BOSS_H    = 0.00;
SCREW_D   = 2.20;     // clearance for M2

// The socket's footprint on the module's back, which the seat has to be
// relieved for. *** POSITION UNMEASURED -- known only to be on the LEFT, so
// this is a generous slot out to the pocket edge rather than a fitted pocket.
CONN_SLOT_V = 9.00;   // how tall a band it takes, centred on the module
CONN_SLOT_U = 14.00;  // how far in from the left pocket edge
// Mirrored on the right as well. Nothing is behind it there -- it is purely
// to open the seat up so the hat can be got past it on the way in.
CONN_SLOT_BOTH = true;
CONN_SLOT_OVER = 0.60; // past the pocket wall, leaving 1.1 of rim

// The display's screws run along the screen normal, which at 70 degrees is
// only 20 degrees off horizontal -- so a driver has to come in almost level
// from behind, and the case floor cuts that line off before it reaches the
// back opening. These are the two channels that let it through, bored on the
// screw axis from just behind each lower boss. They come out as long shallow
// ellipses in the underside, and using them means tipping the case up.
LCD_ACCESS = true;
ACCESS_D   = 5.00;    // 3.60 took a shaft but not a bit
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

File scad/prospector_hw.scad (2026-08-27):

// Measured hardware, shared by every Prospector layout. Nothing in here is
// geometry -- it is the record of what the parts actually are, so that the
// layouts cannot drift apart on the numbers. Provenance for all of it is in
// prospector/REFERENCE.md.

/* [Display -- Waveshare 1.69" Touch LCD, 27057] */
DISP_W    = 39.00;    // from the upstream pocket, 39.09 less clearance
DISP_H    = 31.00;
DISP_T    = 9.96;     // glass to the tops of the module's own standoffs
// *** WAS 3.00, AND IT WAS THE ROOT OF THE CORNER FAULT. Nothing measured it;
// REFERENCE.md carries provenance for every other number here and never
// mentioned this one. Waveshare's panel table gives the corner as R5, and two
// independent things agree with that rather than with 3.00:
//
//   - The pocket is cut to this radius plus DISP_CLR. At 3.00 that is 3.20,
//     about two millimetres squarer than the module at every corner, so the
//     module's round corner sat inside a squarer hole and left a crescent of
//     open pocket. The module's own rim normally hides the pocket -- at 3.00 it
//     covers the corner by 0.865, at R5 by 0.037, and a hair past that the
//     pocket is exposed. That is the gap on the printed part, and it is why it
//     showed at the corners and nowhere else.
//   - Upstream's outer radius of 7.00, long written off here as "the upstream
//     look", is what the concentric identity below returns for a module of
//     about R5. It was never arbitrary. Reading this as 3.00 made 7.00 look
//     2 mm too round, and the correction went the wrong way: it squared the
//     outside down to 4.90, where the frame swells from 0.835 on the flats to
//     1.705 at the corners.
//
// So the identity was right and its input was wrong. STILL WANTS CALIPERS on a
// real corner -- 5.00 is the vendor's figure, not a measurement of this part.
DISP_R    = 5.00;     // corner radius of the module outline

// The module drops in from the FRONT and its lip lands on the case, rather
// than being fed in from behind and trapped by a lip on the case. Read off the
// upstream mount, which counterbores its opening for exactly this: 39.09 x
// 31.09 straight through, stepping out to 41.33 x 33.33 for the last 0.80 mm.
// So the case never sits over the glass at all, and how close the picture runs
// to the module's edge stops mattering.
//
// *** WAS 41.33 x 33.33, WHICH IS THE COUNTERBORE AND NOT THE MODULE. A bore
// is cut oversize so the part drops into it; Waveshare give the module as
// 41.13 x 33.13, so upstream's bore carries 0.10 of clearance a side -- the
// same 0.10 that LIP_CLR adds again for a bore drawn here. Taken as the part
// it understated the frame showing round the lip at 0.735 against upstream's
// 0.835, which read as this case being the tighter of the two. On the real
// module both are 0.835 and they are the same.
LIP_W     = 41.13;    // what rests on the case's front face
LIP_H     = 33.13;
LIP_T     = 0.80;     // 17.00 rim less the 16.20 step
LIP_CLR   = 0.10;
DISP_CLR  = 0.20;     // per side, module to pocket
ACT_W     = 32.58;    // active area, 280 px across at 0.1164 mm pitch
ACT_H     = 27.93;    // 240 px up
HOLE_DX   = 29.93;    // M2 pattern, measured -- not symmetric, see REFERENCE
HOLE_DY   = 22.57;
HOLE_D    = 2.40;

// The module's socket is its tallest point, 11.39 from the glass against 9.96
// to the standoffs, and it sits on the LEFT as you face the screen.
CONN_H    = 1.43;     // how far the socket stands proud of the standoff plane
PLUG_H    = 4.00;     // *** ESTIMATE. How much further a seated plug reaches.
                      // Inferred from the hat's 9.82 stack, not measured.

/* [XIAO nRF52840 on its hat] */
// The XIAO is soldered flat to the hat with no gap; the hat runs past it to
// the south for two mounting holes. USB-C is at the north end and leaves in
// the plane of the board. The hat's socket is on the opposite face and its
// cable leaves perpendicular to the board -- that one fact drives every
// layout decision here.
MCU_W     = 27.00;    // the long axis, the one the USB-C exits along
MCU_D     = 21.90;
MCU_H     = 9.82;     // whole stack, USB-C shell to the hat's socket
// The XIAO and its USB-C sit UNDERNEATH the hat once the assembly is inverted,
// so the hat's board is propped this far above the bottom of the stack. Found
// on the first test print: the screw posts had been drawn up to the stack's
// underside, where there is no board to meet them.
PCB_UP    = 4.30;     // stack bottom to the hat board's underside
MCU_CLR   = 0.30;
USB_W     = 9.50;     // upstream slot, which fits the plug shell with clearance
USB_H     = 3.75;
USB_Z     = 1.60;     // opening centre above the bottom of the stack

/* [Geometry common to the layouts] */
// 55 is the upstream screen angle, measured exactly off its geometry. It is a
// design choice rather than a property of the hardware, so each layout sets its
// own TILT and this is only the reference value.
TILT_UPSTREAM = 55.0;
WALL      = 1.60;
BEZEL     = 1.70;     // material around the module, in the screen plane
LIP       = 1.00;     // how far the front frame overhangs the module face
// Cross-section corner radius -- and it is not the free styling number it was
// taken for. The section is the module's pocket grown by BEZEL on every side,
// so its corners have to be the pocket's corners grown by that same BEZEL, or
// the frame stops being a constant width.
//
// The identity to keep is SEC - 2 * RIM_R == POCK - 2 * POCK_R on both axes --
// one rectangle underneath, two radii, a constant frame. prospector.scad
// measures it and echoes it on every build.
//
// WHAT THIS LINE GOT WRONG ONCE, because it is worth keeping and it is not the
// identity's fault. 7.00 was carried over as "the upstream look" and was
// written off here as free styling upstream could afford, its display sitting
// in a separate `disp_mount` plate. Read against DISP_R = 3.00 it looked 2 mm
// too round: 1.70 of frame on the flats against 0.83 at the diagonal, measured
// off the mesh at 0.829, with the module's lip overhanging the case corner by
// 0.13 with nothing underneath it.
//
// Every one of those numbers is a consequence of DISP_R being 3.00, and the
// module's corner is about 5. On the real module the frame at 7.00 was already
// uniform, and the correction squared the outside to 4.90 -- where the frame
// runs 0.835 on the flats and swells to 1.705 at the corners, the same fault
// mirrored. Upstream had not been careless; the radius was concentric with the
// module all along, and it is what this identity returns for a module of R5.
//
// The lesson is not about corners. A derived number is only as good as what it
// derives from, and this one derived from the one figure in the file that
// nothing had ever measured.
RIM_R     = DISP_R + DISP_CLR + BEZEL;   // 6.90, concentric with the pocket

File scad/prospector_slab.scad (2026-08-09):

// Prospector dongle case -- layout C, the slab.
//
// Display and hat lie back to back, both parallel to the screen, and the whole
// sandwich leans on the desk at the measured 55 degrees. This is the only one
// of the three candidate layouts that keeps the screen angle: the wedge and
// the tail-out-the-back both need the screen steepened before the hat fits.
//
// FRAME. As prospector.scad: +x right facing the screen, +y away from you,
// +z up, z = 0 the desk, and the model symmetric about x = 0.
//
// WHAT DECIDES THIS LAYOUT. Everything hangs on GAP -- the room between the
// module's back and the hat for two plugs and the cable between them. The slab
// is 22.4 + GAP thick along the screen normal, so GAP is not a detail, it is
// the design. At GAP = 2 this is the smallest thing on the table; by GAP = 8
// it is no better than upstream. The plug height is still an estimate, so
// treat the figures here as a sensitivity, not a result.

include <prospector_hw.scad>

/* [What to build] */
part   = "all";       // all | shell | cap
GAP    = 8.00;        // *** the number this layout lives or dies on
cut    = "";          // "" | x | y | z
cut_at = 0;
cut_flip = false;
show_parts = true;

$fa = 2; $fs = 0.4;

TILT   = TILT_UPSTREAM;   // the whole point of this layout
DISP_LIFT = 2.00;     // desk to the lowest point of the pocket
CAP_T  = 1.60;
SEAT   = 2.50;
HAT_V  = 4.55;        // hat's offset up the screen, from centre

/* ---------- derived ---------- */
POCK_W = DISP_W + 2 * DISP_CLR;
POCK_H = DISP_H + 2 * DISP_CLR;
POCK_R = DISP_R + DISP_CLR;
SEC_W  = POCK_W + 2 * BEZEL;
SEC_H  = POCK_H + 2 * BEZEL;

W_RIM  = DISP_T + LIP;                    // front face, w from the module back
W_HAT  = -(GAP + MCU_H);                  // hat's far face
W_BACK = W_HAT - CAP_T;                   // outside of the back
SLAB_T = W_RIM - W_BACK;

// The slab has to clear the desk twice over: the module's pocket must not dip
// below the floor, and neither must the hat's lower-back corner, which is the
// part that actually digs in because it is furthest back along the normal.
CZ_DISP = DISP_LIFT + POCK_H / 2 * sin(TILT);
CZ_HAT  = WALL - (HAT_V - MCU_D / 2 - MCU_CLR) * sin(TILT) - W_BACK * cos(TILT);
CZ = max(CZ_DISP, CZ_HAT);
CY = SEC_H / 2 * cos(TILT) + W_RIM * sin(TILT);

echo(str("slab ", SLAB_T, " thick along the normal, GAP ", GAP));
echo(str("height driven by ", CZ_HAT > CZ_DISP ? "the HAT's back corner" : "the display", ", CZ ", CZ));

/* ---------- primitives ---------- */

module rrect(w, h, r) { offset(r = r) square([w - 2 * r, h - 2 * r], center = true); }

module band(w, h, r, w0, w1, dv = 0) {
    translate([0, CY, CZ]) rotate([TILT, 0, 0])
        translate([0, dv, w0]) linear_extrude(w1 - w0) rrect(w, h, r);
}

module desk(floor = 0) {
    translate([-100, -100, floor]) cube(200);
}

/* ---------- the case ---------- */

module outer() {
    intersection() { band(SEC_W, SEC_H, RIM_R, W_BACK, W_RIM); desk(); }
}

module hollow() {
    band(POCK_W, POCK_H, POCK_R, 0, DISP_T);                       // module
    band(POCK_W - 2 * LIP, POCK_H - 2 * LIP,                       // window
         max(POCK_R - LIP, 0.5), DISP_T, W_RIM + 1);
    intersection() {                                               // cavity
        band(SEC_W - 2 * WALL, SEC_H - 2 * WALL, RIM_R - WALL,
             W_BACK, -WALL);
        desk(WALL);
    }
}

// USB-C leaves along the hat's long axis, so it goes out the side wall. That
// is the price of this layout and there is no way round it: the port is on
// the board edge and the board is parallel to the screen.
module usb_slot() {
    translate([0, CY, CZ]) rotate([TILT, 0, 0])
        translate([SEC_W / 2, HAT_V - MCU_D / 2 + USB_Z + MCU_CLR,
                   W_HAT + MCU_H / 2])
            cube([WALL * 6, USB_H, USB_W], center = true);
}

module mcu_box() {
    band(MCU_W + 2 * MCU_CLR, MCU_D + 2 * MCU_CLR, 1.0,
         W_HAT, W_HAT + MCU_H, HAT_V);
}

module shell() {
    difference() {
        outer();
        hollow();
        mcu_box();
        usb_slot();
        band(200, 200, 0.1, W_BACK - 60, W_BACK + CAP_T);          // cap slab
    }
}

module cap() {
    difference() {
        intersection() { outer(); band(200, 200, 0.1, W_BACK, W_BACK + CAP_T); }
        usb_slot();
    }
}

/* ---------- the hardware, for looking at ---------- */

module ghost_display() {
    color("SteelBlue", 0.55) band(DISP_W, DISP_H, DISP_R, 0, DISP_T);
    color("DimGray", 0.35)   band(ACT_W, ACT_H, 1.5, DISP_T, DISP_T + 0.1);
}
module ghost_mcu() {
    color("DarkSalmon", 0.6) band(MCU_W, MCU_D, 1.0, W_HAT, W_HAT + MCU_H, HAT_V);
}

module assembly() {
    if (part == "all" || part == "shell") color("Gainsboro") shell();
    if (part == "all" || part == "cap")   color("DarkSalmon") cap();
    if (show_parts && part != "cap") { ghost_display(); ghost_mcu(); }
}

module keep() {
    B = 500; o = cut_flip ? -B : 0;
    if (cut == "x") translate([cut_at + o, -250, -250]) cube(B);
    else if (cut == "y") translate([-250, cut_at + o, -250]) cube(B);
    else if (cut == "z") translate([-250, -250, cut_at + o]) cube(B);
}

if (cut == "") assembly();
else difference() { assembly(); keep(); }

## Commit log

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2026-08-01 Add STL verification tools
    Two pure-numpy scripts for measuring the OpenSCAD output against the printed
    STLs, so the port can be checked by number rather than by eye.
    stlstat.py reports bbox, volume, shell count and edge manifoldness. It
    reproduces the figures already published in the root README exactly, which is
    how it is known to be measuring correctly.
    slice.py compares cross-sectional area at given heights. Volume says how much
    two parts differ; this says where -- a constant delta across a z band means the
    section is wrong, a varying delta means the reference has features the
    candidate lacks.
2026-08-01 Split rim and skirt wall thickness
    The printed parts do not share a wall thickness. Probing scan lines at
    y = 40/60/80 on both x sides gives 1.550 mm at the top rim and 1.600 mm at the
    bottom skirt, consistently. The single WALL = 1.55 was therefore correct for
    the rim and 0.05 mm light on the skirt, so cavity_2d() now takes the inset as
    an argument and the bottom passes WALL_SKIRT. The mountains sit inside the rim
    boundary and keep 1.55, which the reference bbox confirms (128.317 / 241.050
    is exactly the outline inset by 1.55).
    The skirt now matches the reference to 0.002 mm on the probed lines.
    Worth recording how this was nearly got wrong: the first estimate came from
    dividing cross-sec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
2026-08-01 Add countersinks, bridge slots, and the mountain clip
    All four changes were measured off the printed top rather than assumed, and
    each now matches the reference to within 0.03 mm on the probed scan lines.
    Countersinks: probing the bore every 0.2 mm at both (148.042, 68.846) and
    (184.042, 68.846) gives the radius growing exactly 1:1 with z -- 1.35 at
    z=3.0, 1.95 at z=3.6 -- so the wall is 45 deg, 90 deg included, reaching
    4.30 dia at the plate top face. Cut in 3D, with the overshoot continuing the
    same slope so the diameter at Z_PLATE_TOP stays exact.
    Bore is 2.40, not the 2.2 that was assumed here. Switch cutouts are 13.95,
    not 13.90 -- every cutout edge sat 0.025 mm inside the reference u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
2026-08-01 Model the plate underside: flare, slot floor, pocket
    Takes the top from +2.1% to +0.34% by volume against the printed part.
    Three features that a section at z=3.0 cannot see, because none of them
    reaches above z=2.6. This is why earlier passes kept reporting the plate as
    correct: every check had been taken at a height where it was.
    The switch cutouts flare toward the underside on their x edges only. Probed
    every 0.1 mm, the flare is 0.000 at z=2.60 and grows exactly 0.100 per 0.100
    of z, reaching 1.000 per side at the underside -- a true 45 deg wall. The y
    edges stay at 13.95 the whole way down, so this is not a uniform chamfer and
    cannot be done with a scaled extrude; the cut is built as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
2026-08-01 Add boundary extractor; record what the bottom's fill is not
    The bottom is now the largest remaining error at -8.8%. The missing material
    is solid fill in the four regions where the rectangular outline runs outside
    the PCB's curved edge. It is prismatic -- the boundary does not move between
    z=-1.9 and z=1.5 -- so one 2D profile would describe it.
    Two candidate rules were tested and both fail, which is worth recording so
    they are not tried again: it is not a uniform offset of pcb_outline
    (perpendicular distance to the stored polyline varies from 0.75 to 4.58 mm),
    and it is not offset(-WALL_SKIRT) of the case outline, which is what the file
    does today. The measured boundary has straight runs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
2026-08-02 Fix the screw keep-out shape; add tools/render.py
    The keep-out was an octagon. It is a square turned 45 degrees -- every face a
    diagonal, no axis-aligned ones.
    This survived the entire port. The difference is two slivers of about 0.5 mm2
    per screw, under every threshold worth setting, and invisible in volume, bbox
    and section area alike; the mountains read -0.04% with it wrong. It is
    unmissable in a picture: the printed keep-out presents one long unbroken 45
    degree face, and the octagon's 0 and 90 faces chop that same diagonal into a
    short run with square shoulders either end. The user spotted it by eye. Three
    sub-threshold clusters disappear with the diamond, and the rendered outline now
    m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
2026-08-02 Add section views, and a one-command export
    Section views because they are the check that works when there is nothing to
    diff against. Of the seven real errors in this port, six were interior -- the
    switch cutout flare below z=2.6, the bridge slot floor, the underside pocket,
    the cavity floor fillet, the standoff fillets, the two skirt thicknesses. None
    are visible from outside a closed solid at any render quality, so a better
    viewer would not have found them; only the screw keep-out was catchable by
    looking. `cut = "x"|"y"|"z"` slices the model, cut_at defaults to the middle of
    that axis, cut_flip keeps the other half.
    tools/render.py --cut wires it up and swings the camera to an elevation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
2026-08-02 Hold the hat with hooks, and close the open items
    The hat is now held down as well as located: two tongues reach 1.5 mm back
    over its front corners, so it goes in from the back, slides forward under
    them, and the rear cap closes behind it. Constrained in every direction
    without needing its mounting holes, whose spacing is not known -- a post in
    the wrong place would foul the board rather than hold it. The USB-C through
    the cap slot pins the far end. Costs 22 mm2 of support.
    Also adds two posts to zip-tie the cable bundle down, clear of the seat's
    screw bosses. Posts rather than a bar over the floor: a bar would be a 43 mm
    bridge and this part already needs support for its roof.
    tools/overh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
    [prospector.scad]
2026-08-02 Screw the hat down: both hole positions now measured
    Centre-to-centre 17.10, from two straddling spans -- 19.2 over the far walls
    and 15.0 between the near ones. Their mean is the centre distance and cancels
    the hole diameter; their half difference gives it back as a check, 2.10, which
    is exactly an M2 clearance hole, so both spans were taken on centre. A
    photograph had said 16.80.
    Centre 2.65 from the south edge, from 1.60 to the near wall. A first reading
    of 16 was caught by the geometry rather than by eye: the strip south of the
    XIAO is only 6.0 wide, so a centre has to fall between 1.05 and 4.95 of that
    edge, and 16 puts the hole inside the XIAO's footprint from either end.
    Posts stand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
    [prospector.scad]
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2026-08-03 Bolt the hat after all: strip the seat, carve the insertion volume
    Three faults, all of them the same shape -- geometry that was correct about
    the space a part occupies and wrong about the space it needs to get there.
    The tray carved only the hat's real profile, which left a shelf under its bare
    strip at z = 6.0 with the XIAO hanging to 6.3. The assembly could travel
    0.3 mm before fouling, so it could only ever drop straight in, and the hooks
    needed it to slide. mcu_box() is the full brick again; hat_top_at() keeps the
    thin profile for the clearance checks. Insertion volume and occupied volume
    are different things and the model now says so.
    The seat was a 7.25 ring holding nothing. The mod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
    [prospector.scad]
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2026-08-03 Step the hat's profile at the socket, not at the XIAO
    The XIAO hangs underneath and does not raise the hat's top at all -- what
    stands tall is the socket, 7.10 from the south edge, measured. The profile was
    stepping up at the XIAO's edge, 6.00, which is the wrong feature.
    It changes no result, and that is the useful part: the clearance never binds
    at the socket. Sampled along the hat at 55 degrees the gaps run 0.99, 5.81,
    10.63, 11.53, 18.26 ... -- the minimum is at the hat's FRONT corner, where its
    top is the bare board at 7.90 and the display's underside is at 8.89. The
    socket's worst gap is 11.53, an order of magnitude clear.
    So refining the socket's footprint cannot help. What blocks a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
    [prospector.scad]
2026-08-03 Stop subtracting a seat wall that is not there any more
    The clearance over the hat was measured as pocket_z - WALL, which was wrong
    twice over. WALL is the seat's thickness along the screen normal; straight
    down it is WALL / cos(TILT), 2.79 at 55 degrees rather than 1.6. And the seat
    is no longer a plate: cutting it back to a rim opened the window over
    |v| <= POCK_H/2 - SEAT, so above the hat there is no plate at all and the
    ceiling is the module itself.
    Over the hat's front corner at 55 degrees that is 2.59 mm of real clearance
    against a reported 0.99. Found by being told the space was plainly visible on
    the assembled part, which it was.
    It moves every angle: 70 goes 4.90 -> 6.50, and 55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
    [prospector.scad]
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2026-08-03 Measure the cable's headroom from the hat, not from the socket
    You measured 20 mm from the hat. The check was taking it from the top of the
    socket, 3.92 mm higher -- an extra requirement with nothing behind it, and the
    only thing making a shallower screen fail this test.
    With the datum right, 60 degrees fits at lift 4 and comes out 37.83 tall
    against 70's 38.71, and 55 at lift 4 is 37.00 and misses nothing but the
    ceiling clearance, by 0.41.
    Also noted at the definition: it is a conservative proxy either way. It asks
    for 20 mm straight up when the bundle can turn into any part of a 37 cm3
    cavity, so a near miss here is worth looking at rather than a verdict.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
    [prospector.scad]
2026-08-03 Set the screen to 55 degrees, the upstream angle
    43.2 x 43.0 x 37.0, 45.16 cm3, 11.60 cm3 of plastic. Against upstream's
    43.2 x 51.4 x 38.0 and 59.86: same width, 16% shallower, 1 mm shorter, 25%
    less enclosed volume, 27% less filament -- at the same screen angle.
    SLACK 3.00 -> 2.50. It binds at the hat's bare front corner, under the
    display's lower rim and 7 mm forward of where the socket starts. Nothing but
    air passes there, and 3.00 was a number I picked; it was costing 15 degrees of
    screen angle.
    CONN_NEED stops carrying the bundle's 15 mm. That ray checks the plug behind
    the module's socket; the bundle is checked by the headroom test, in the
    direction it actually travels. Asking both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
    [prospector.scad]
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2026-08-03 Close the roof, then make it part of the cap
    Two things, and the first was a hole rather than a design gap.
    The chamfered roof had no material behind it at all. The cavity's chamfer was
    written as CH_Z + WALL + CH_M * (y - back) with back = DEPTH + 1, which put it
    2.71 mm ABOVE the outer skin instead of 2.39 below. So the top of the back was
    simply missing, and looked like a panel nobody had drawn yet. trim() now takes
    an explicit perpendicular inset and always references the chamfer to DEPTH, so
    moving the back plane cannot tilt the roof.
    Then the roof joins the cap, which the display forced. Its upper screws run
    along the screen normal; with the roof fixed the driver's line is blocked by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
    [prospector.scad]
2026-08-03 Tighten the rear cap's pilot, and drive it from one number
    The screws went straight through, which is the post's pilot rather than the
    cap: the cap's hole is clearance by design and the screw is meant to bite
    behind it. 2.10 for an M2.5 is 0.84 of the major diameter, slack before print
    tolerance is counted at all.
    CAP_SCREW now picks the screw and the clearance and pilot follow at +0.20 and
    x0.78 -- 2.70 and 1.95 for M2.5, 2.20 and 1.56 for M2. Set it to 2.00 if these
    are M2, which would explain a 2.10 hole offering nothing to bite on.
    The first attempt at this edit silently did not match, and the model kept
    building the old sizes. Caught by sectioning the post rather than by rereading
    the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
    [prospector.scad]
2026-08-03 The rear cap takes M2, the same screw as the display
    Which is the whole explanation for screws passing straight through: the pilot
    was 2.10, above an M2's own major diameter, so there was nothing to cut into.
    It had been sized for the M2.5 the upstream BOM lists, and this build does not
    use those anywhere.
    CAP_SCREW = 2.00 now drives both, at +0.20 clearance and x0.80 pilot: 2.20
    through the cap, 1.60 into the post. Sectioned to confirm rather than trusted
    -- 2.183 and 1.577 as built.
    Also refreshes two stale claims in the header that would have misled anyone
    reading it: the printing figures predated several changes, and it still said
    the screen was at 70 to buy depth back.
    Co-Authored-By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
    [prospector.scad]
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2026-08-03 Shorten the hat rails to the rear, and turn them back on
    Run the full length of the hat they reached forward into the display's screw
    holes. They only need to stop the hat's free end lifting -- the two screws hold
    the front -- so RAIL_LEN takes them back 10 mm from the hat's rear edge. That
    leaves 14.6 mm between the rails and the hat's screws.
    [prospector.scad]
2026-08-04 Keep the roof on the shell forward of y = 30
    Left to the chamfer alone the cap's roof ran forward to y = 19.76, and the
    display face's top edge is at 19.96 -- so with the cap off the case was open
    right up to the back of the screen. SPLIT_Y stops the cap's roof short and the
    shell keeps everything ahead of it.
    It costs nothing. The driver for the upper display screws leaves the roof plane
    at y = 39.95, so an opening starting at 30 still clears it by 10 mm; it only
    has to be absent where the driver actually crosses, which is right at the back.
    Cap goes from 23.2 deep to 13.0 and from 2.71 cm3 to 2.02.
    [prospector.scad]
2026-08-04 Pull the hat rails clear of the rear cap's posts
    Running to the hat's back edge put the rails alongside the cap's screw posts
    for 6 mm with 1.25 between them. Not touching, but close enough to read as a
    collision, and there is no reason for the rails to be back there -- the cap
    closes behind the hat anyway.
    RAIL_BACK stops them 8 short of the hat's back edge, so they run y 25.4..33.4:
    cap posts 2.0 mm clear
    access channels 3.5 mm clear
    hat screws 6.4 mm clear
    Ending them at 35.4, exactly where the posts begin, gave 0.0 -- which is the
    coplanar case that has produced a separate shell, a non-manifold edge and a
    sliver already in this project. Not again.
    Co-Authored-B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
    [prospector.scad]
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2026-08-04 Stop the tray's kerbs short of the display's access bores
    The rails over the hat go off for good -- the two screws hold it, and the
    rails' undersides were 107 mm2 of ledge to support for retention already
    covered.
    The kerbs were a separate problem and the one that was visible on the part:
    the display's lower access bores come down through the tray's outer corners,
    so a full-length kerb comes out notched. The tray is now a pad plus a kerb
    block that starts at KERB_Y, derived from where the bore has dropped clear
    below the tray rather than typed in.
    Shell 9.81 cm3, cap 2.03, both one shell with no boundary or non-manifold
    edges. Print orientations re-measured; desk-down still wins for the sh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
    [prospector.scad]
2026-08-04 Split the back into a roof tile and a back plate
    One bent panel reads well and prints badly. The vertical back wants to stand on
    its bottom edge; the roof wants to lie flat. Bent together one of them always
    loses, and the one that lost was the roof -- face-down on the build plate, which
    is the face on show.
    Split at the bend, with no third screw. The shell keeps the inner half of the
    chamfer for JOINT past the seam and the tile's front tongue lies on that ledge;
    the back plate keeps the outer half as a lip with a rib under it, so the tile's
    rear tongue runs into a groove. A tongue captured above and below cannot
    rotate, so the front cannot lift, so the front only needs a ledge. Releasing it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
    [prospector.scad]
2026-08-04 Open the rear pilot to the one that has actually been driven
    1.60 was 0.8 x major, the textbook thread-forming pilot, and it asked an M2 to
    form 4.4 mm of thread in one go. The driver cammed out before the plate was
    down and the head then crushed into 1.6 mm of plate -- the same fault seen from
    the other end, not a second one.
    1.70 is not a calculation. It is what the hat's screws use: same screw, same
    plastic, same wall, and the only pilot in this case that has been driven
    without complaint. Both come off M2_PILOT now.
    CAP_FREE bores the post's mouth to clearance for 1 mm, so the screw forms
    3.4 mm of thread instead of 4.4 and finds the hole square first. The bore's lip
    is broken by 0.30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
    [prospector.scad]
2026-08-04 Root the back plate's rib in solid plate, not in a 0.15 mm neck
    The rib stopped level with the groove's end, where the plate body is only the
    outer CAP_T -- so its entire attachment was the sliver of plate left below the
    groove, 0.15 mm of it. One shell, no non-manifold edges, no boundary edges: the
    mesh checks cannot see this at all. A side elevation showed it at a glance.
    The rib now runs past the groove to RIB_Y and roots over 1.11 mm of a 2.4 mm
    section. How far it can run is set by the hat underneath, so RIB_Y is derived
    from the hat's top rather than typed, and echoed with the clearance it lands on.
    Cutting the groove out of the lap section alone, before the rib is unioned on,
    is wha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
    [prospector.scad]
2026-08-04 Revert to the one-piece cap
    The split into a roof tile and a back plate worked -- ledge at the front,
    groove at the rear, captive without a third screw -- but it needs a 1.6 mm
    plate split three ways to make the joint: lip 0.80, groove 0.80, tongue 0.65,
    rib hanging below. No margin in any of it, and the rib was rooted in 0.15 mm of
    neck until a side elevation caught it. Not worth one face's finish.
    Keeps what the split turned up and does not depend on it:
    - M2_PILOT at 1.70, CAP_FREE's lead-in and the broken bore lip, which are
    what fixed the rear screws actually driving badly
    - the driver clearance at the top display screws, 5.61 mm, now echoed --
    it is the reason the cap car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
    [prospector.scad]
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2026-08-05 Drop the screen a millimetre closer to the desk
    DISP_LIFT 4 -> 3. The case comes down with the display: 36.37 tall to 35.37,
    for nothing in depth or width. Enclosed volume 43.92 -> 42.40 cm3, plastic
    11.98 -> 11.48.
    What it spends is margin, and both gates fall 1:1 with it:
    lift 4 36.37 tall hat 3.70 cable 21.38
    lift 3 35.37 hat 2.70 cable 20.38 <- want 2.5 and 20
    lift 2 34.37 hat 1.70 cable 19.38 both fail
    Depth does not buy lift 2 back. Lowering the display lowers the whole
    cross-section, so the ceiling over the hat comes down with it; at DEPTH 46 the
    hat recovers to 3.90 and the cable is still 19.64.
    Re-checked at the new height rather than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
    [prospector.scad]
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2026-08-05 Reset access: a hole through the floor, and the rails back to take the press
    Reverses an earlier note in REFERENCE.md that said not to spend geometry on
    this. The button had gone unused for months; it is wanted now.
    It goes through the FLOOR. The XIAO hangs under the hat and the stack is
    inverted, so the component side the button sits on faces the case's underside.
    Upstream's cantilever tab in the rear cap was for a bare XIAO the other way up
    and does not transfer. A plain hole rather than a plunger or a sprung tab: the
    floor's top is at 1.6 and the button is around z = 3 to 4, so anything captive
    would bridge a couple of millimetres of air and rattle for years to save
    reaching for a paperc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
    [prospector.scad]
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2026-08-08 Reset access as a slot, so it need not be aimed
    A pin hole has to find a button about 2 mm across, and neither number needed to
    aim one is known well enough. Measured from two datums that agree -- 0.5 from
    the board's edge, 2.85 from the connector's face, the difference being a 2.35
    Type-C overhang -- but whether either is to the centre or the near edge is not
    settled, and the offset across the board is not measured at all.
    So the floor is cut away instead: a strip 18 wide from y = 38.1 back to the
    shell's rear edge, open at the back. The y datum stops mattering and the width
    covers the lateral uncertainty.
    It gives up almost nothing, because the underside is filleted at the back and
    that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
    [prospector.scad]
2026-08-08 Lap the roof seam instead of butting it
    The cap seats by travelling forward until its back plate meets the shell at
    y = 41.4. Its roof tip arrived at y = 30 in the same instant, because both were
    cut on that one plane -- two faces, in different planes, both required to close
    at once, on two parts printed separately. On the part the tip landed first, the
    back plate could not close, and the roof bent backwards. That is the gap.
    I had checked shell against cap, found they only touched, and called it a butt
    joint located by two screws. Right about the back plane, blind to this one: a
    face square to the direction of travel must not touch before the seating face
    does, and a zero-volume intersecti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
    [prospector.scad]
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2026-08-24 Check the printable STLs in under release/
    The repository is the sync channel between machines, and building from
    source needs OpenSCAD installed. So the two exports are committed: a
    git pull now puts the printable parts on disk.
    They come with the figures to check them against -- shell 9.5354 cm3,
    cap 1.9026 cm3, one shell each, zero boundary edges -- because the
    failure mode here is silent. Nothing rebuilds them, so anything that
    moves the geometry has to rebuild both in the same commit, and an STL
    that is merely stale looks exactly like one that is current.
    Two notes recorded with them. The shell must be exported with
    show_parts=false or the ghosted display and XIAO go into the file, wh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
    [prospector_cap.stl, prospector_shell.stl]
2026-08-24 Measure the module's corner, and put RIM_R back where it was
    DISP_R said 3.00. Nothing had ever measured it -- REFERENCE.md carries
    provenance for every other number about this module and never mentioned
    this one -- and Waveshare's panel table gives the corner as R5.
    That one figure is upstream of everything the last corner fix concluded,
    and at R5 the whole account inverts.
    THE GAP ON THE PRINTED PART WAS THE POCKET, NOT THE OUTSIDE. The pocket is
    cut to DISP_R + DISP_CLR, so at 3.00 it was 3.20 -- about two millimetres
    squarer than the module at every corner. The module's round corner sat in
    a squarer hole and left a crescent of open pocket, which is what the
    photograph shows. It was mar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
    [prospector_cap.stl, prospector_hw.scad, prospector_shell.stl]
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2026-08-27 Split the seam's two clearances, and tighten only the one on show
    SEAM_CLR was doing both ends of the lap at 0.30, and they are not the same
    problem.
    One end is the tongue's tip against the shell's roof end at SPLIT_Y. It sits
    under the lap where nothing can see it, and it is the clearance that bent
    the roof backwards when it was zero. That one stays at 0.30.
    The other is the cap's shoulder, where its skin steps back up to full
    thickness against the trailing end of the lap. Neither part owns the roof
    across it, so it is the line the seam note admits to -- and it is wider than
    the note implies, because the gap is cut in y and read on a 45 degree face:
    it shows 1/cos of itself, 0.42 mm at 0.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
    [prospector.scad, prospector_cap.stl, prospector_shell.stl]
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
